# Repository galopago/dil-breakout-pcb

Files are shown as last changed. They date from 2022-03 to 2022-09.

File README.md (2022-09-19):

# BREAKOUT BOARDS FOR RF MODULES

Open source breakout boards for "stamp like" rf modules. Good for experimenting on a breadboard or to be used as sub-boards.

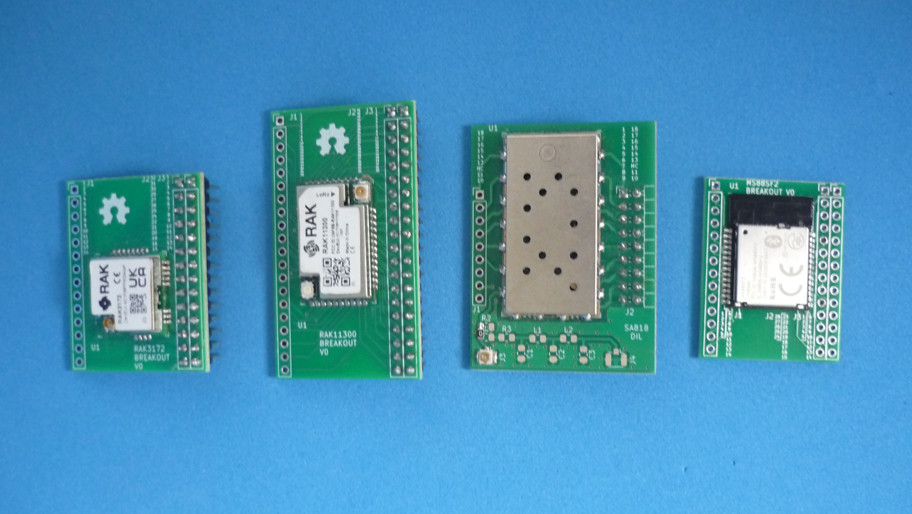
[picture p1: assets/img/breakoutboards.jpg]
BREAKBOARDS


Read this in other languages: [Español](/assets/markdown/README.es.md)

Main features:

* Every pin is accessible
* Compatible with solderless breadboard
* Double row header for maximizing free space on prototype boards

Breadboard                              | Space saver right angle                    | Space saver rised                           
----------------------------------------|--------------------------------------------|---------------------------------------------
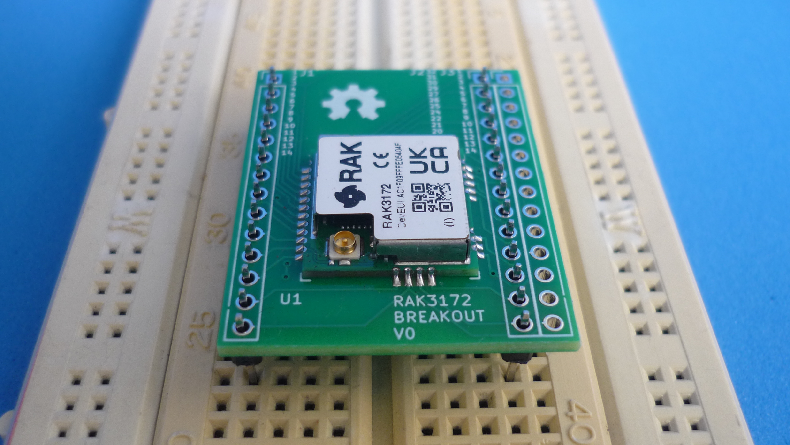
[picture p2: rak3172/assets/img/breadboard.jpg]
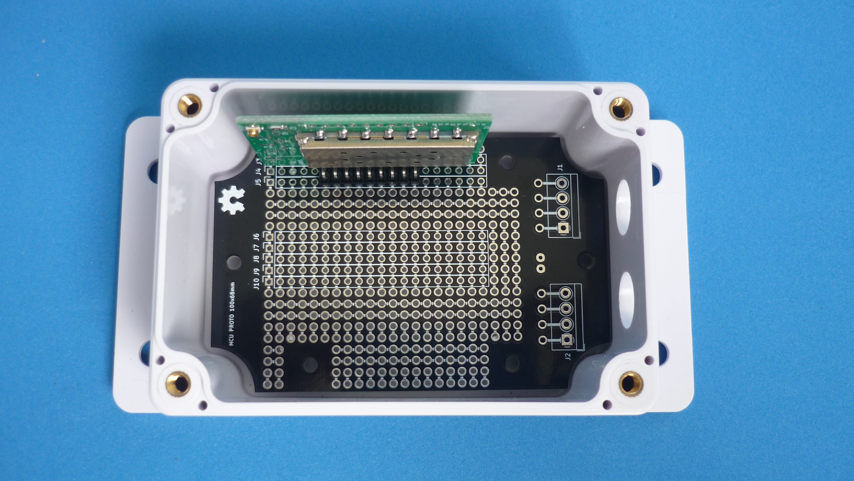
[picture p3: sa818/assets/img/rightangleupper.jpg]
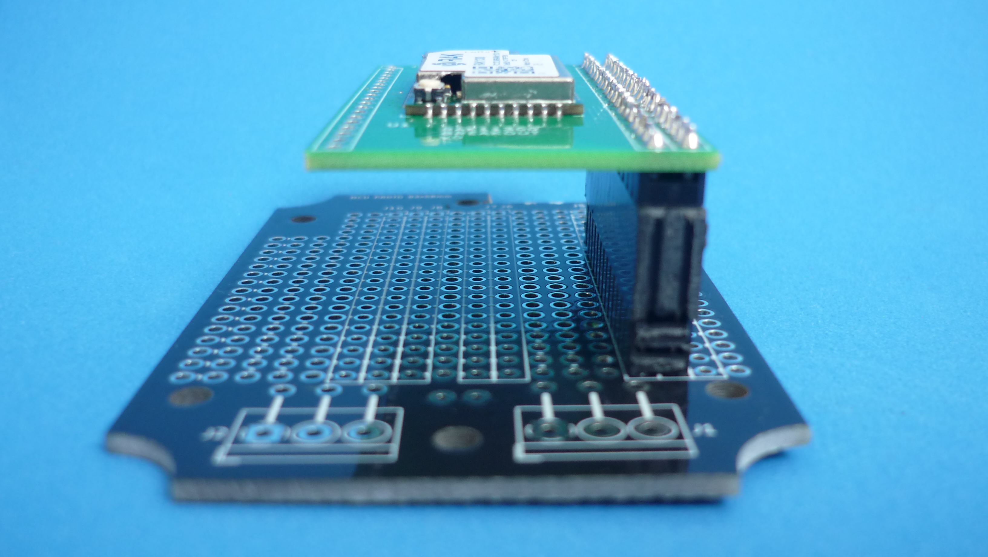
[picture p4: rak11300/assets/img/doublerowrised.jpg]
 |  | 

## Versions

There are several board versions, each one with different personalities

| HINT | CHIP | LINK 
|---|---|---
| RAK3172  | STM32WLE5CC | [RAK3172](/rak3172)  
| RAK11300 | RP2040+SX1262 | [RAK11300](/rak11300)  
| SA818 | RENESAS MCU ?+RDA1846 | [SA818](/sa818)
| MS88SF2  | nRF52840 | [MS88SF2](/ms88sf2)

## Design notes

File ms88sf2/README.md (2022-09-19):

# BREAKOUT BOARD FOR MS88SF2 MODULE

This board allows [Minew MS88SF2 modules](assets/pdf/MS88SF2.pdf) to be used on breadboard for prototyping. Open source and manufacturing files available. The main features are:

* Every pin is accessible
* Compatible with solderless breadboard
* Double row header for maximizing free space on prototype boards

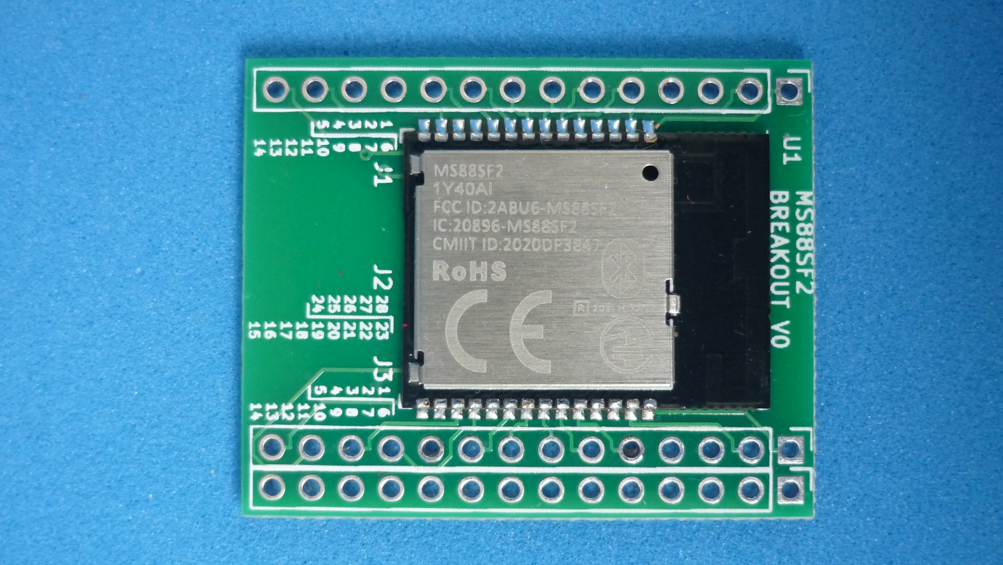
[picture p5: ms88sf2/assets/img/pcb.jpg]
PCB


## How to use this repository

The PCB was developed in KiCad V5.1,

## Directory structure

* The root folder contains template KiCad files: project, schematic and PCB 
* /library folder contains additional symbols needed to edit printed schematic
* /modules folder contains additional footprints needed to edit printed circuit board
* /gerber folder contains ready to manufacture files.
* /assets folder contains support files for reade.md

## PINOUT

layout

## BREADBOARD

Pitch compatible with solderless breadboard

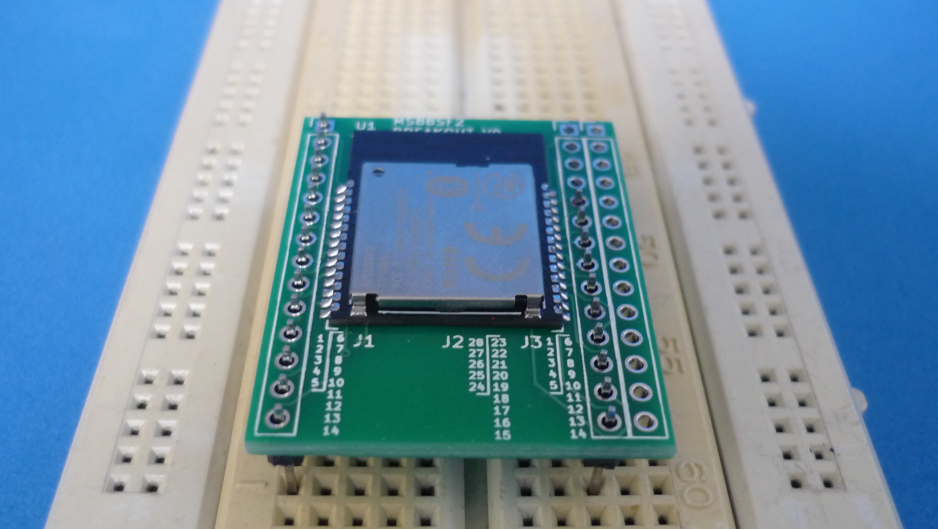
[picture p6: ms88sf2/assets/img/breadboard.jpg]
BREADBOARD


## DOUBLE ROW RIGHT ANGLE

Space saver option when enclosure's height allows it

 FRONT                             | SIDE                             | UPPER                            
-----------------------------------|----------------------------------|-----------------------------------
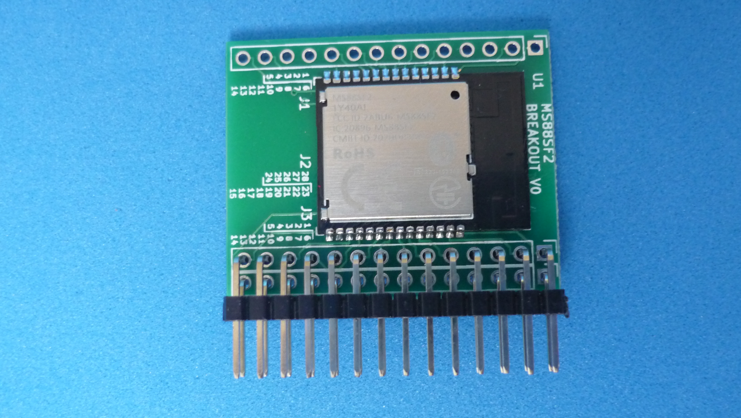
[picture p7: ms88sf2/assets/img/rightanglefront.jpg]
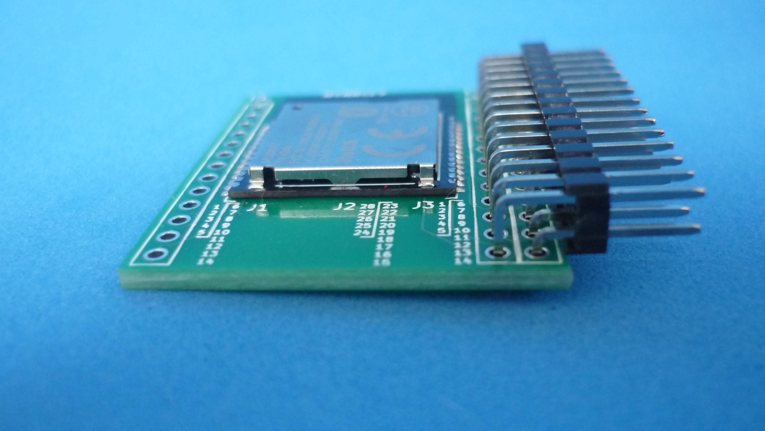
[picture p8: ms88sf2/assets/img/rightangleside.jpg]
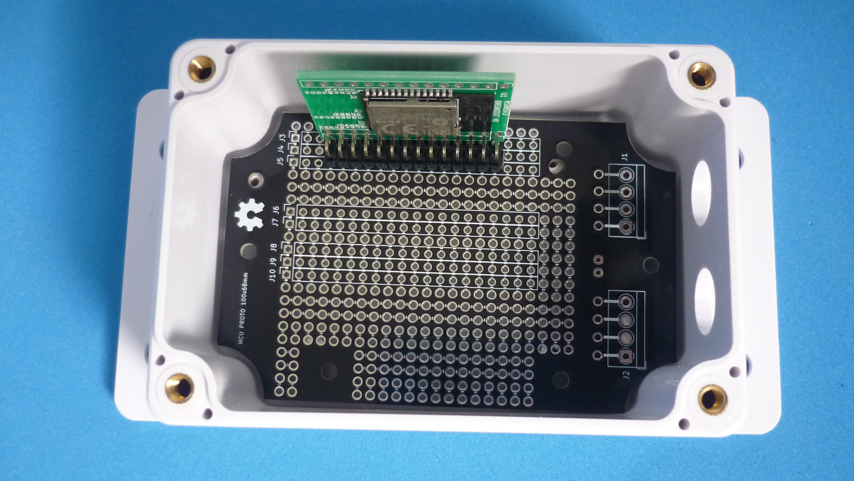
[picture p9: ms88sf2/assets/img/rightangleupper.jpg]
||

## DOUBLE ROW RISED

Space saver option for batteries or additional electronics. Uses long pin headers with spacers to reach the maximun allowable height

 SIDE                              | RISED                          
-----------------------------------|--------------------------------
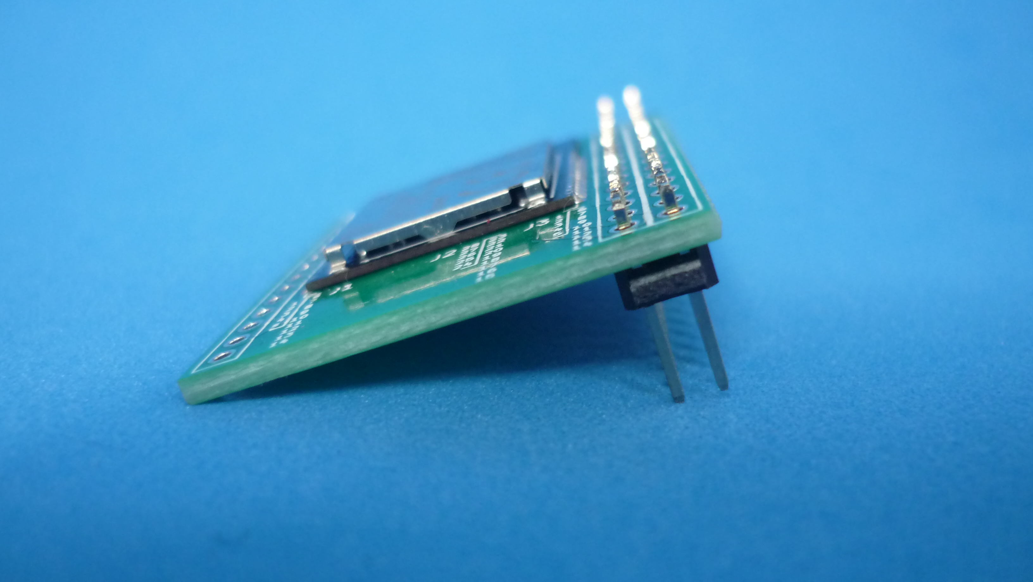
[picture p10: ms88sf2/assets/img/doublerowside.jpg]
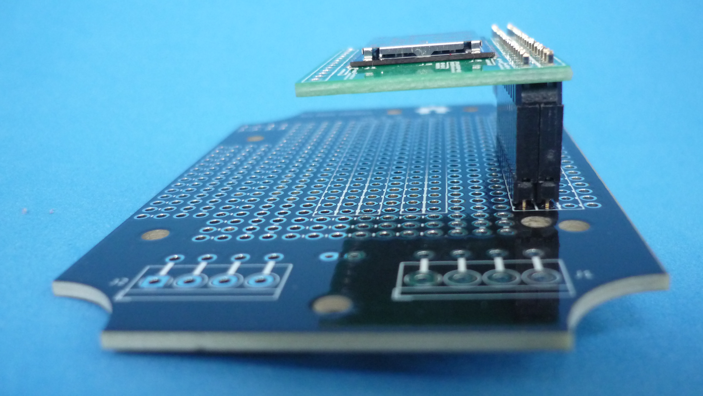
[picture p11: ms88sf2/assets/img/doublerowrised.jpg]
|

## PCB

 SINGLE                            | PANEL                          
-----------------------------------|--------------------------------
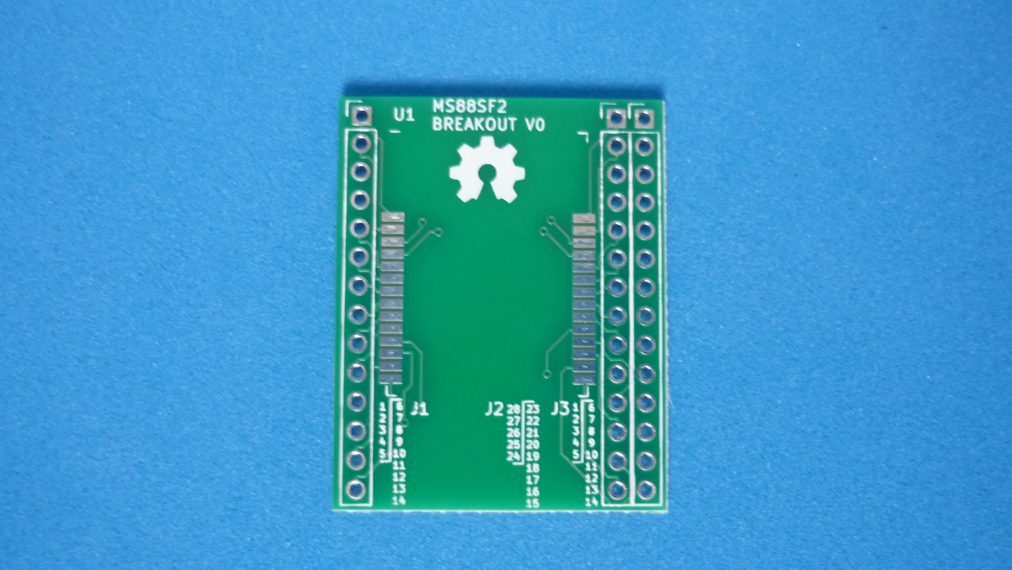
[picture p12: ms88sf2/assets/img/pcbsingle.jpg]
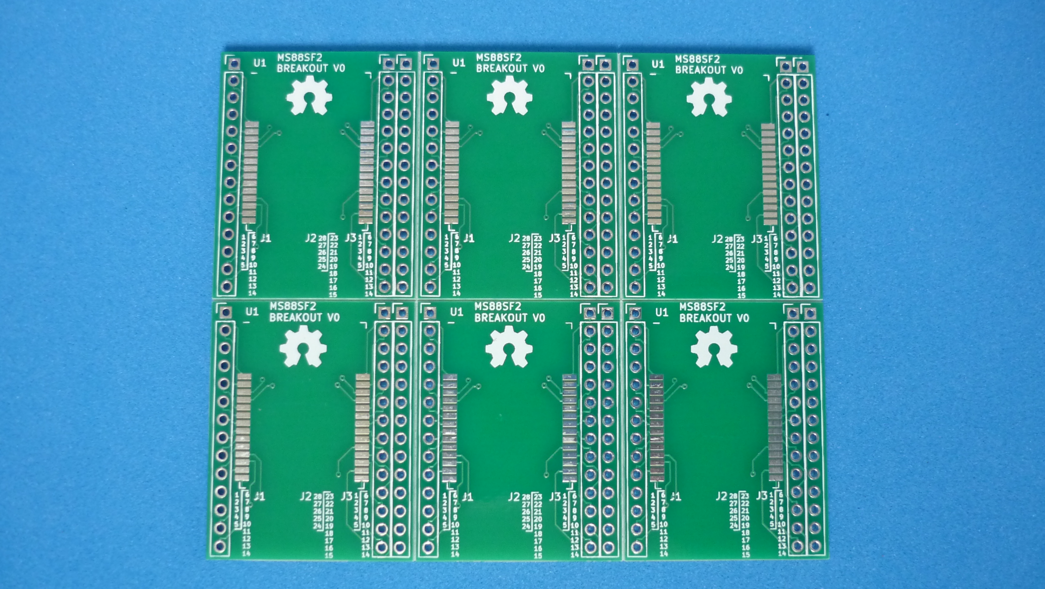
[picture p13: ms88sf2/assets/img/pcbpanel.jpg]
|

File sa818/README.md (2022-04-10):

# BREAKOUT BOARD FOR SA818 MODULE

This board allows [NiceRF SA818 modules](assets/pdf/SA818.pdf) to be used on breadboard for prototyping. Open source and manufacturing files available. The main features are:

* Every pin is accessible
* Compatible with solderless breadboard
* Double row header for maximizing free space on prototype boards
* Pads for U.Fl RF connector
* Pads for custom output pi filter

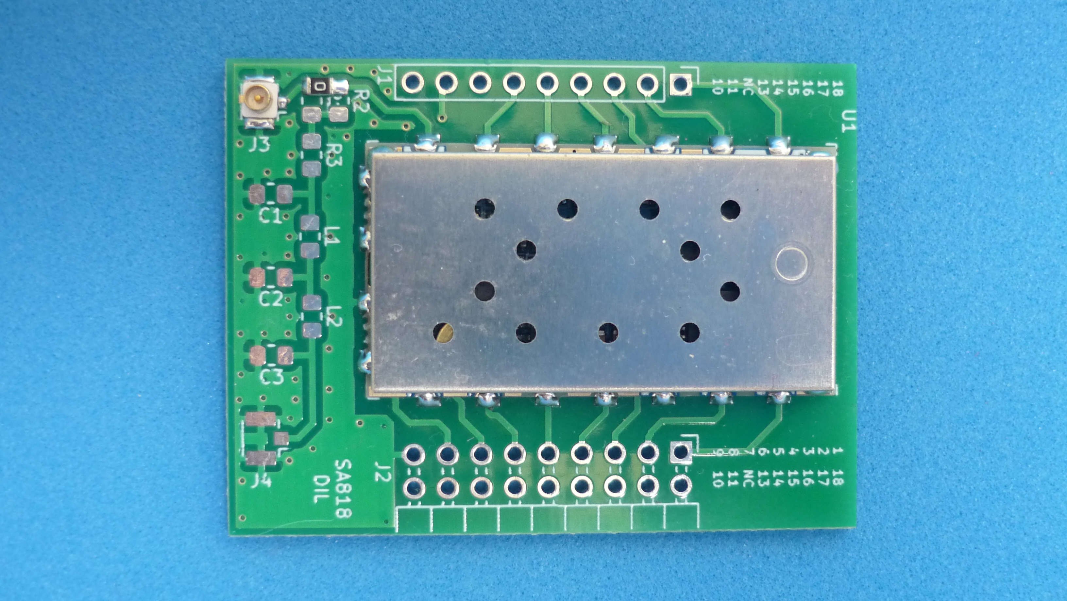
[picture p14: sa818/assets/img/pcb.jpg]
PCB


## How to use this repository

The PCB was developed in KiCad V5.1,

## Directory structure

* The root folder contains template KiCad files: project, schematic and PCB 
* /library folder contains additional symbols needed to edit printed schematic
* /modules folder contains additional footprints needed to edit printed circuit board
* /gerber folder contains ready to manufacture files.
* /assets folder contains support files for reade.md

## PINOUT

layout

## BREADBOARD

Pitch compatible with solderless breadboard

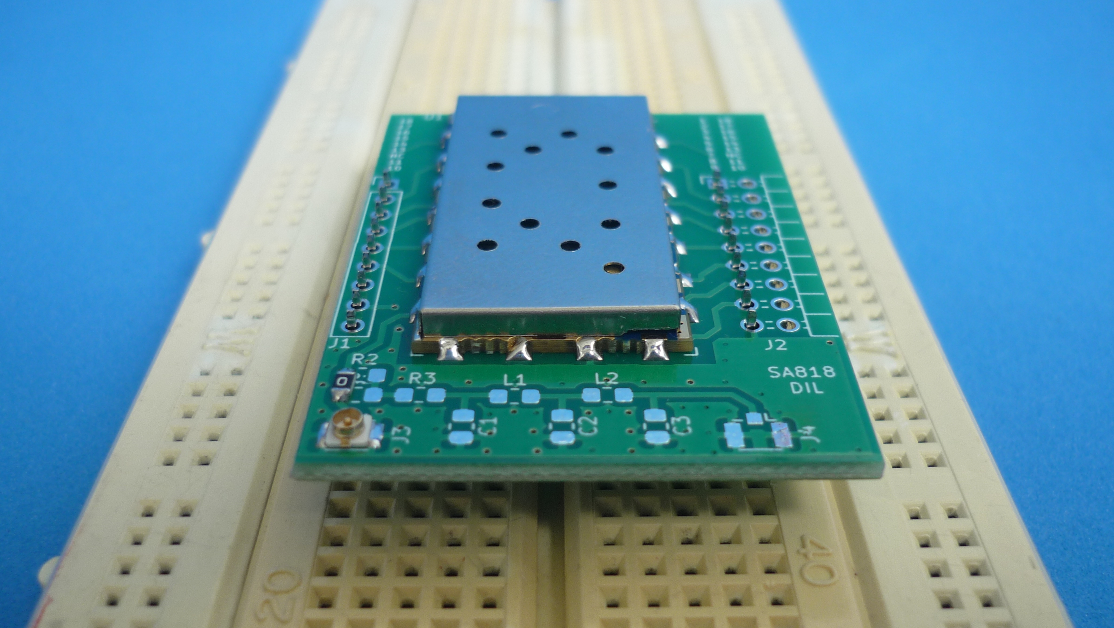
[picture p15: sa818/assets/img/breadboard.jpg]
BREADBOARD


## DOUBLE ROW RIGHT ANGLE

Space saver option when enclosure's height allows it

 FRONT                             | SIDE                             | UPPER                            
-----------------------------------|----------------------------------|-----------------------------------
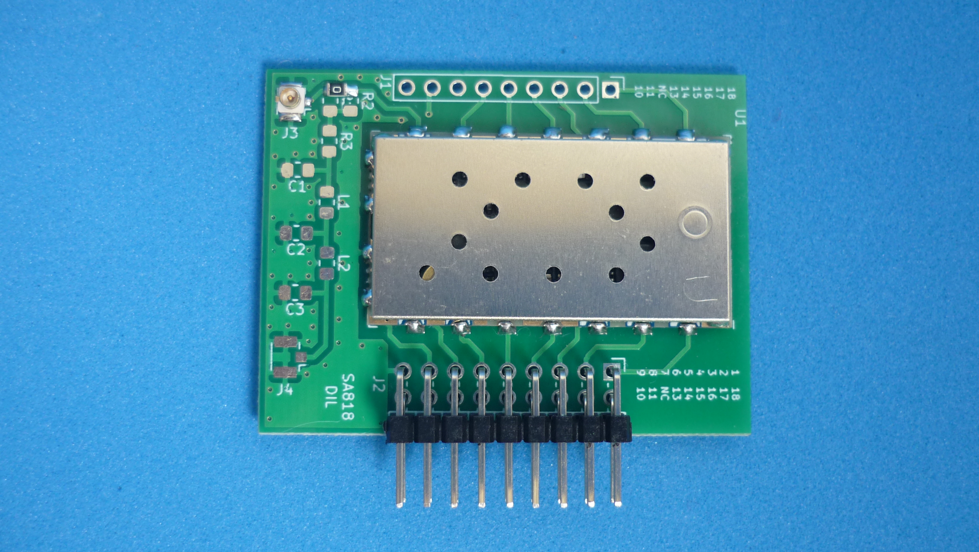
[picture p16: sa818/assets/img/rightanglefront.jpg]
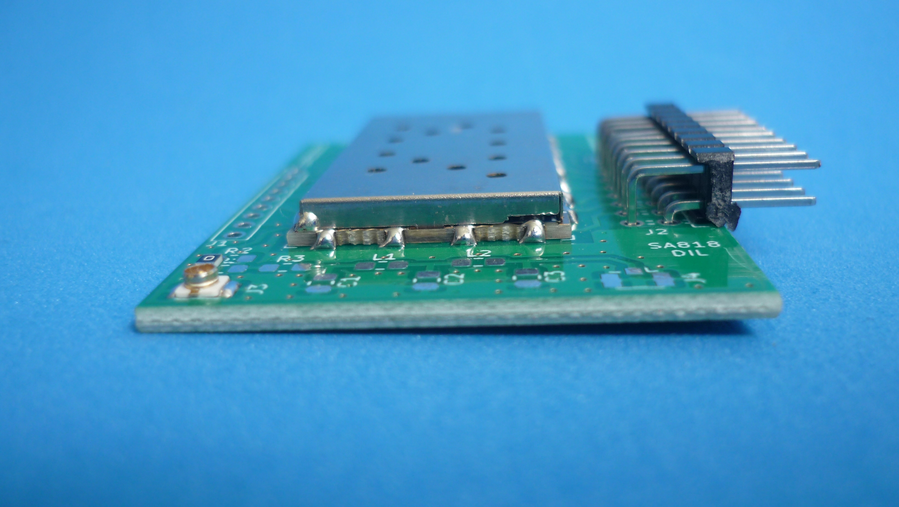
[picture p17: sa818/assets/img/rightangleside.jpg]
||

## DOUBLE ROW RISED

Space saver option for batteries or additional electronics. Uses long pin headers with spacers to reach the maximun allowable height

 SIDE                              | RISED                          
-----------------------------------|--------------------------------
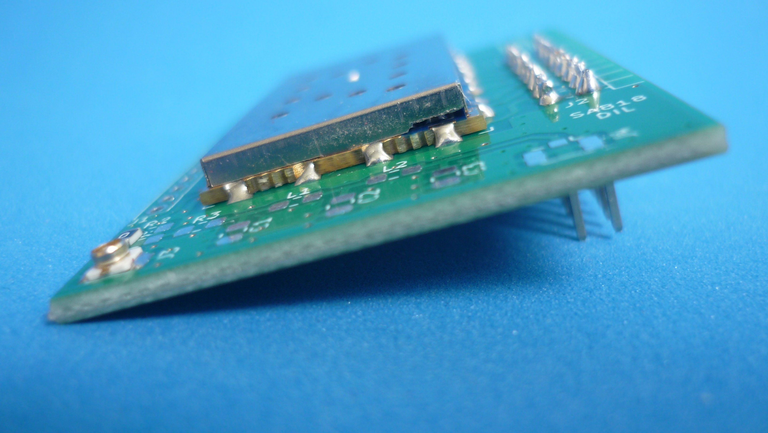
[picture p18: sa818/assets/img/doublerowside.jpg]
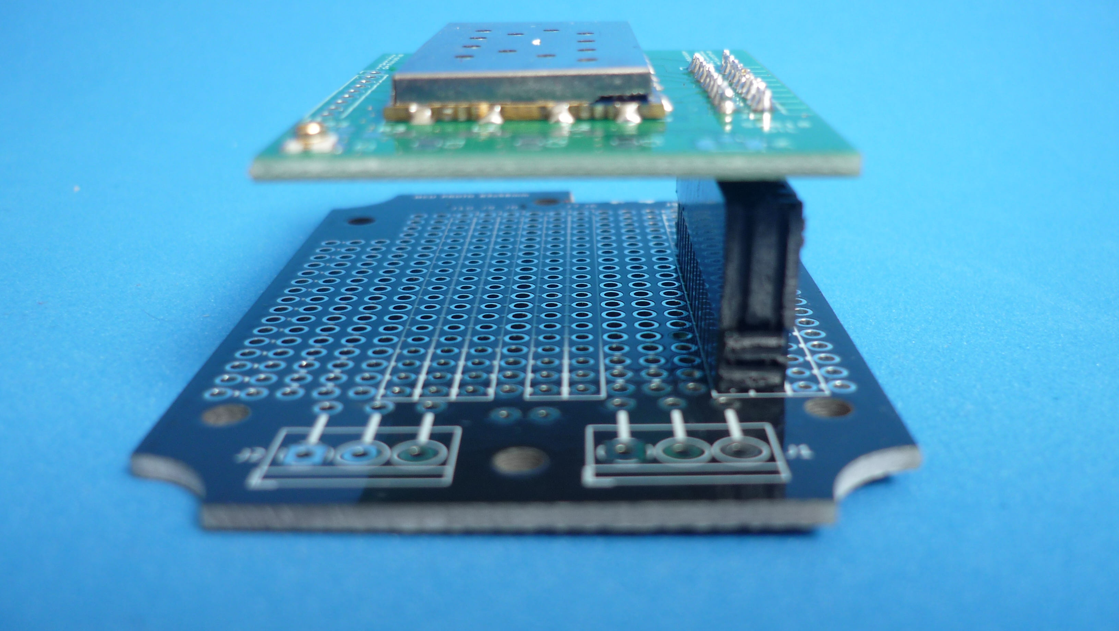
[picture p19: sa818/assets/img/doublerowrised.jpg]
|

## PCB

 SINGLE                            | PANEL                          
-----------------------------------|--------------------------------
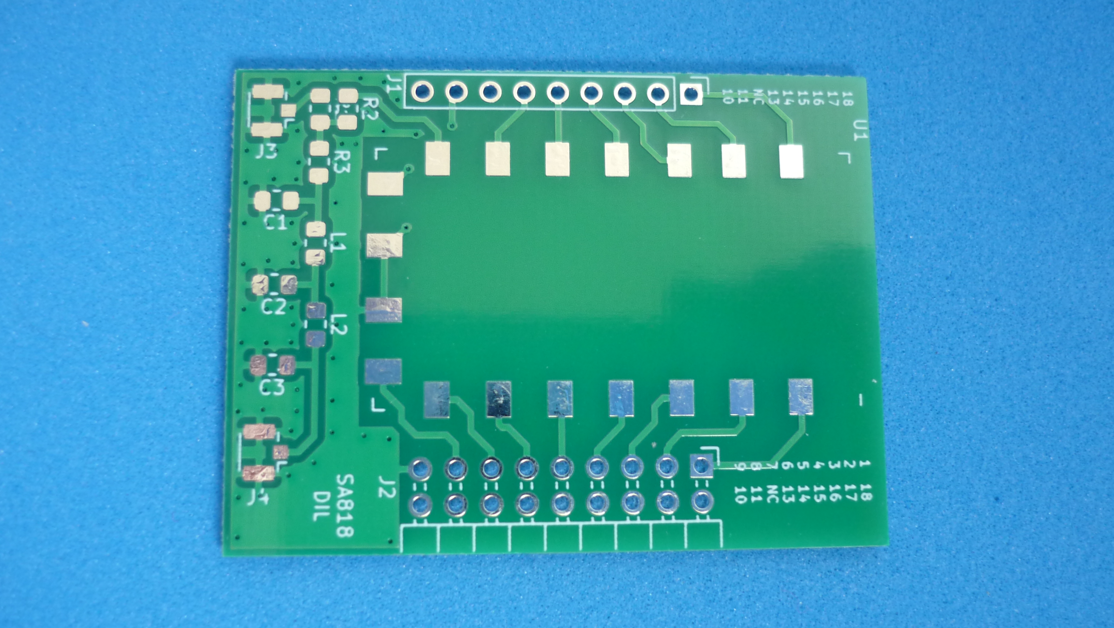
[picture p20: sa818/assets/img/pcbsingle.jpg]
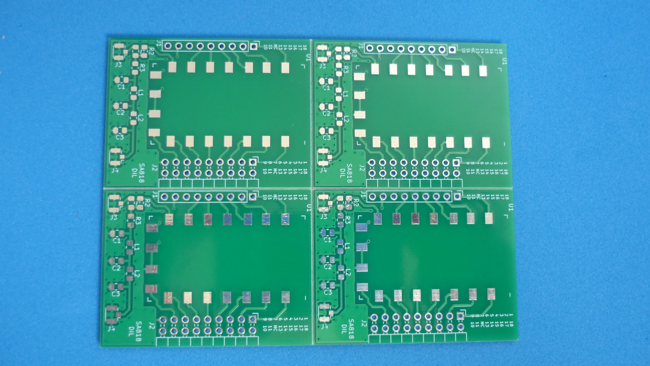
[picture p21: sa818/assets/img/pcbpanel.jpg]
|

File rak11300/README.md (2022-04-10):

# BREAKOUT BOARD FOR RAK11300 MODULE

This board allows [RAK Wireless 11300 modules](assets/pdf/RAK11300.pdf) to be used on breadboard for prototyping. Open source and manufacturing files available. The main features are:

* Every pin is accessible
* Compatible with solderless breadboard
* Double row header for maximizing free space on prototype boards

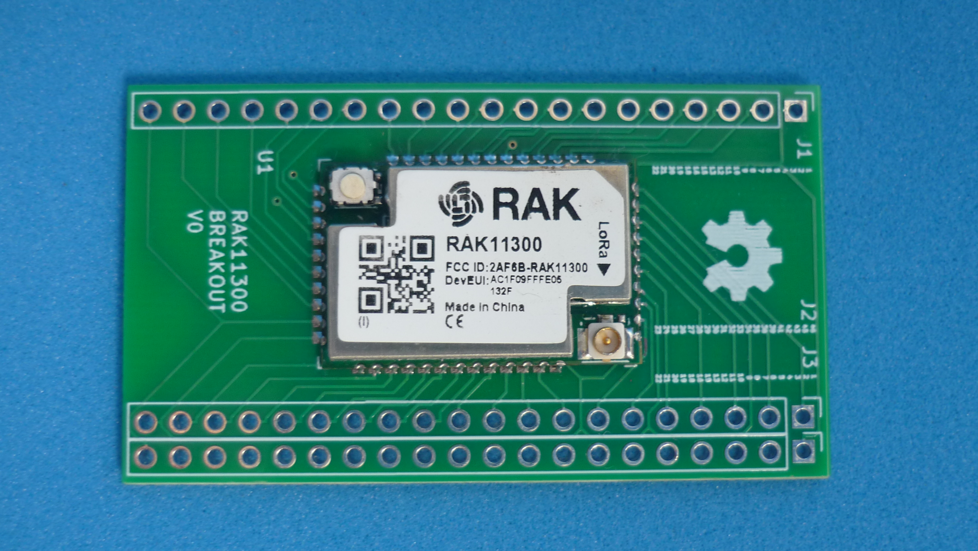
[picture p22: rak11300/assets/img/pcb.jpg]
PCB


## How to use this repository

The PCB was developed in KiCad V5.1,

## Directory structure

* The root folder contains template KiCad files: project, schematic and PCB 
* /library folder contains additional symbols needed to edit printed schematic
* /modules folder contains additional footprints needed to edit printed circuit board
* /gerber folder contains ready to manufacture files.
* /assets folder contains support files for reade.md

## PINOUT

layout

## BREADBOARD

Pitch compatible with solderless breadboard

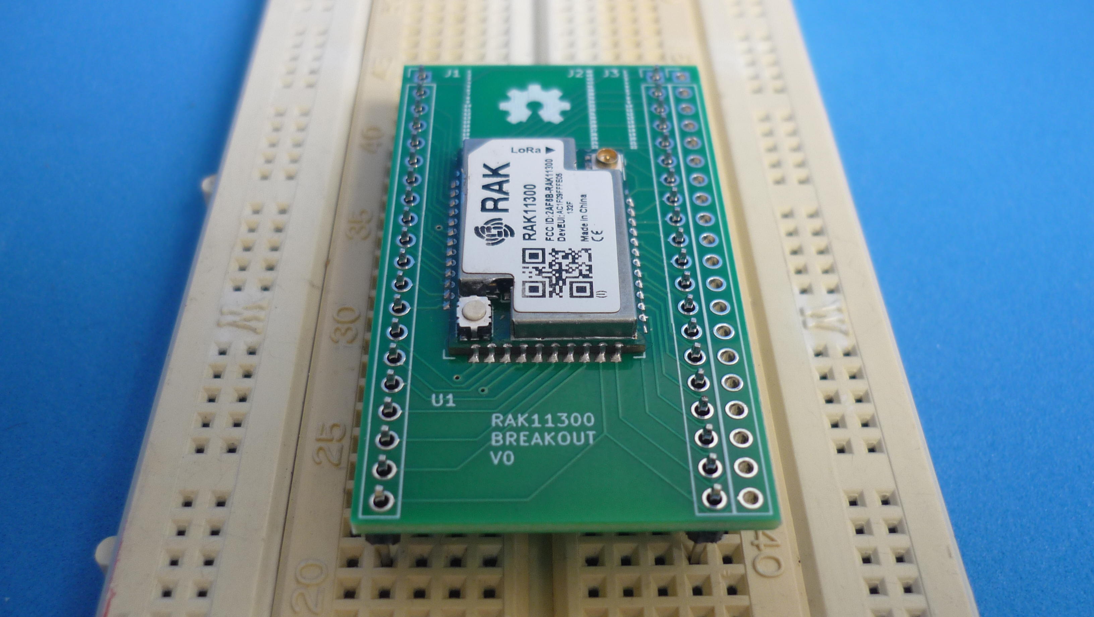
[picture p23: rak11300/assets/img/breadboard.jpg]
BREADBOARD


## DOUBLE ROW RIGHT ANGLE

Space saver option when enclosure's height allows it

 FRONT                             | SIDE                             | UPPER                            
-----------------------------------|----------------------------------|-----------------------------------
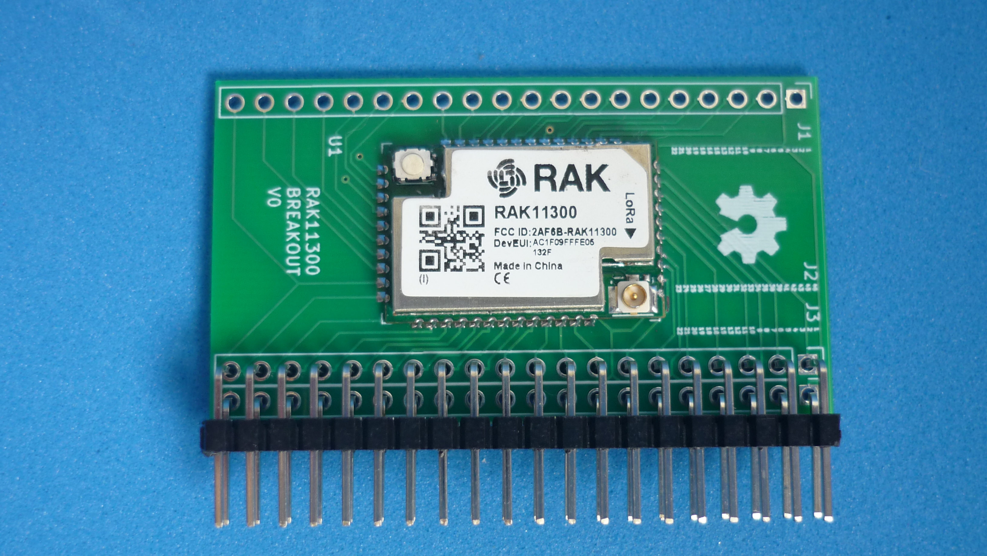
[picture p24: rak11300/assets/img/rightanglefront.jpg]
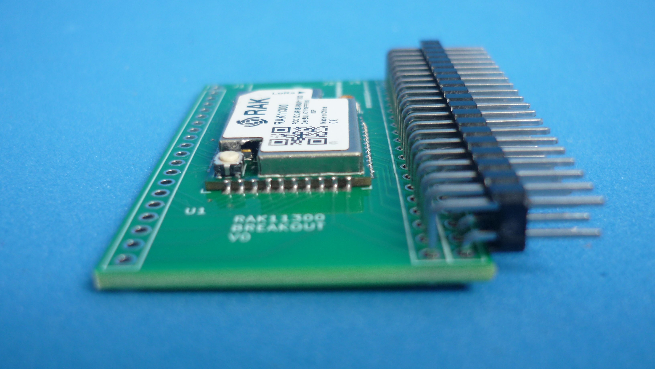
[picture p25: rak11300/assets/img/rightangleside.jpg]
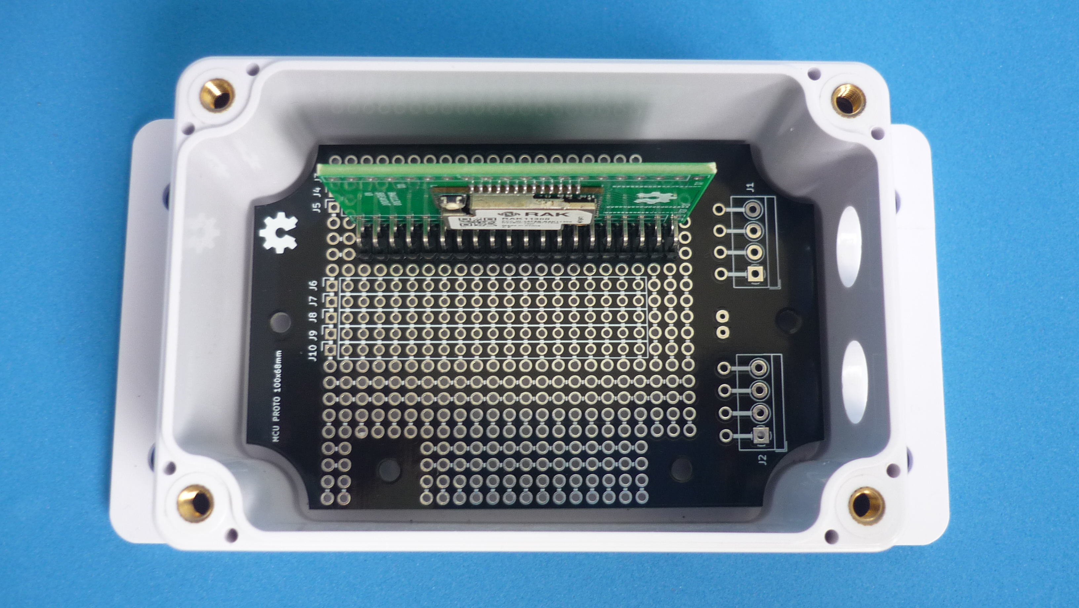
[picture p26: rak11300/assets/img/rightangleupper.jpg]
||

## DOUBLE ROW RISED

Space saver option for batteries or additional electronics. Uses long pin headers with spacers to reach the maximun allowable height

 SIDE                              | RISED                          
-----------------------------------|--------------------------------
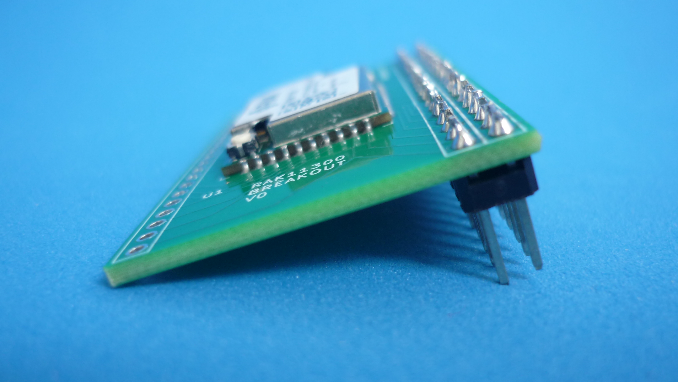
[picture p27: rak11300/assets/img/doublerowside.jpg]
|

## PCB

 SINGLE                            | PANEL                          
-----------------------------------|--------------------------------
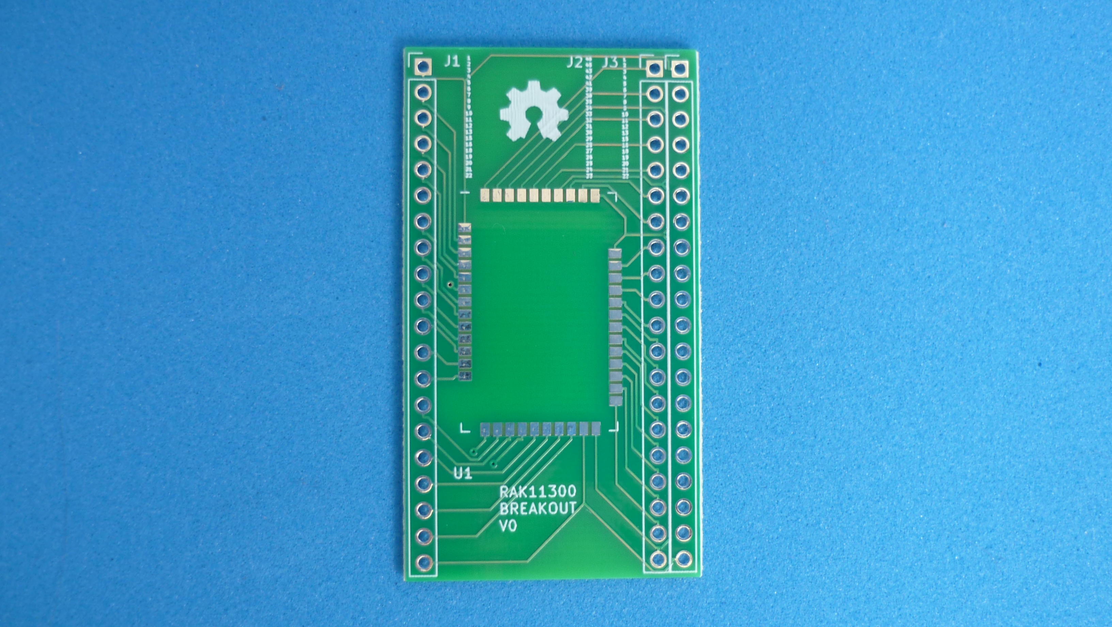
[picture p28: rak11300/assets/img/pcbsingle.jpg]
|

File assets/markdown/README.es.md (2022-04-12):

# TARJETA BREAKOUT PARA MODULOS RF

Tarjeta breakout Open source para modulos rf tipo "estampilla". Utiles para experimentar en protoboard o para ser usada como sub-tarjeta.

BREAKBOARDS

Lea esto en otros idiomas: [English](../../README.md)

Principales caracteristicas:

* Todos los pines son accesibles
* Compatible con protoboards
* Header de doble hilera para maximizar el espacio libre disponible en tarjetas de prototipado

Protoboard                              | Modo economiza espacio 90 grados           | Modo economiza espacio elevado
----------------------------------------|--------------------------------------------|---------------------------------------------
 |  | 

## Versiones

Existen varias versiones de la tarjeta, cada una tiene su propia personalidad

| DESCRIPCION | CHIP | ENLACE 
|---|---|---
| RAK3172 | STM32WLE5CC | [RAK3172](/rak3172)  
| RAK11300 | RP2040+SX1262 | [RAK11300](/rak11300)  
| SA818 | RENESAS MCU ?+RDA1846 | [SA818](/sa818)

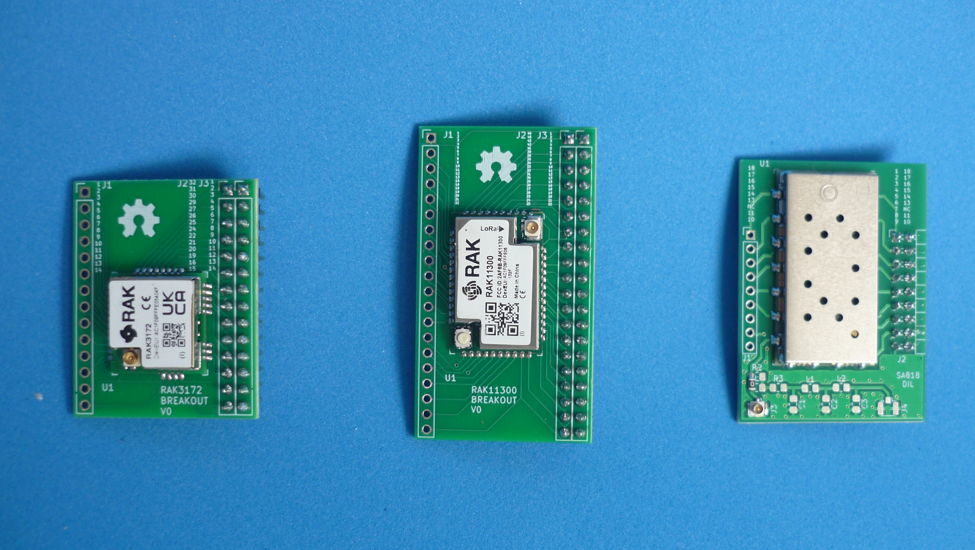
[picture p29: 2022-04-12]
assets/img/_breakoutboards.jpg

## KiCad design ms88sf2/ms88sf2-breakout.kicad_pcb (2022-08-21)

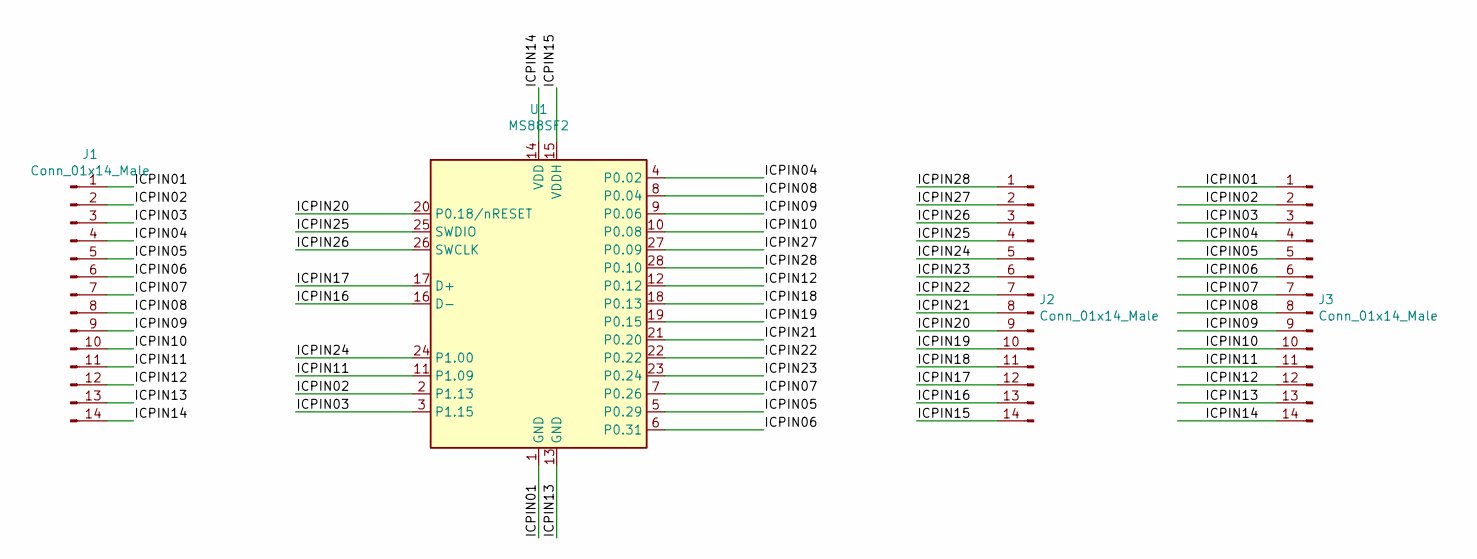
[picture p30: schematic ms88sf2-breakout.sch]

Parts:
J1, J2, J3: Conn_01x14_Male; PinHeader_1x14_P2.54mm_Vertical
U1: MS88SF2

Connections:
/ICPIN01: J1.1, J3.1, U1.1 (GND)
/ICPIN02: J1.2, J3.2, U1.2 (P1.13)
/ICPIN03: J1.3, J3.3, U1.3 (P1.15)
/ICPIN04: J1.4, J3.4, U1.4 (P0.02)
/ICPIN05: J1.5, J3.5, U1.5 (P0.29)
/ICPIN06: J1.6, J3.6, U1.6 (P0.31)
/ICPIN07: J1.7, J3.7, U1.7 (P0.26)
/ICPIN08: J1.8, J3.8, U1.8 (P0.04)
/ICPIN09: J1.9, J3.9, U1.9 (P0.06)
/ICPIN10: J1.10, J3.10, U1.10 (P0.08)
/ICPIN11: J1.11, J3.11, U1.11 (P1.09)
/ICPIN12: J1.12, J3.12, U1.12 (P0.12)
/ICPIN13: J1.13, J3.13, U1.13 (GND)
/ICPIN14: J1.14, J3.14, U1.14 (VDD)
/ICPIN15: J2.14, U1.15 (VDDH)
/ICPIN16: J2.13, U1.16 (D-)
/ICPIN17: J2.12, U1.17 (D+)
/ICPIN18: J2.11, U1.18 (P0.13)
/ICPIN19: J2.10, U1.19 (P0.15)
/ICPIN20: J2.9, U1.20 (P0.18/nRESET)
/ICPIN21: J2.8, U1.21 (P0.20)
/ICPIN22: J2.7, U1.22 (P0.22)
/ICPIN23: J2.6, U1.23 (P0.24)
/ICPIN24: J2.5, U1.24 (P1.00)
/ICPIN25: J2.4, U1.25 (SWDIO)
/ICPIN26: J2.3, U1.26 (SWCLK)
/ICPIN27: J2.2, U1.27 (P0.09)
/ICPIN28: J2.1, U1.28 (P0.10)

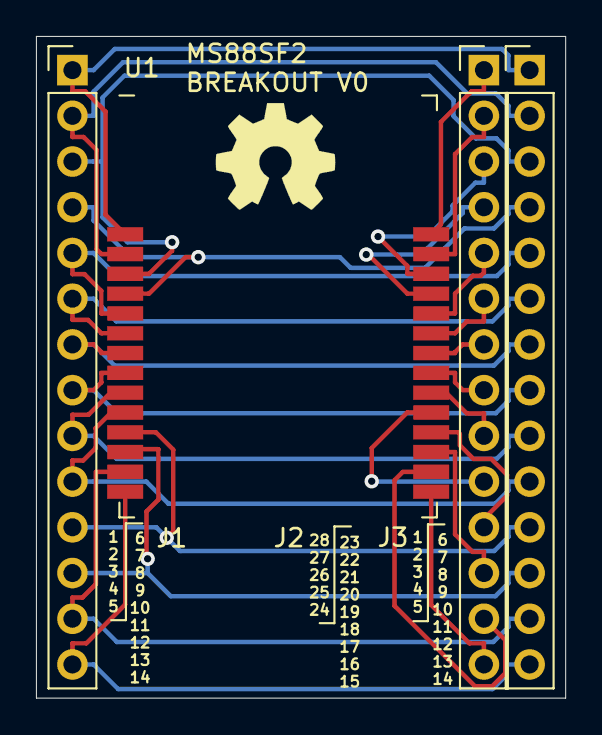
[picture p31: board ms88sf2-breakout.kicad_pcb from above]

Board: 2 copper layers, 29.4 x 36.8 mm, 4 parts (0 on the bottom side), 28 nets.

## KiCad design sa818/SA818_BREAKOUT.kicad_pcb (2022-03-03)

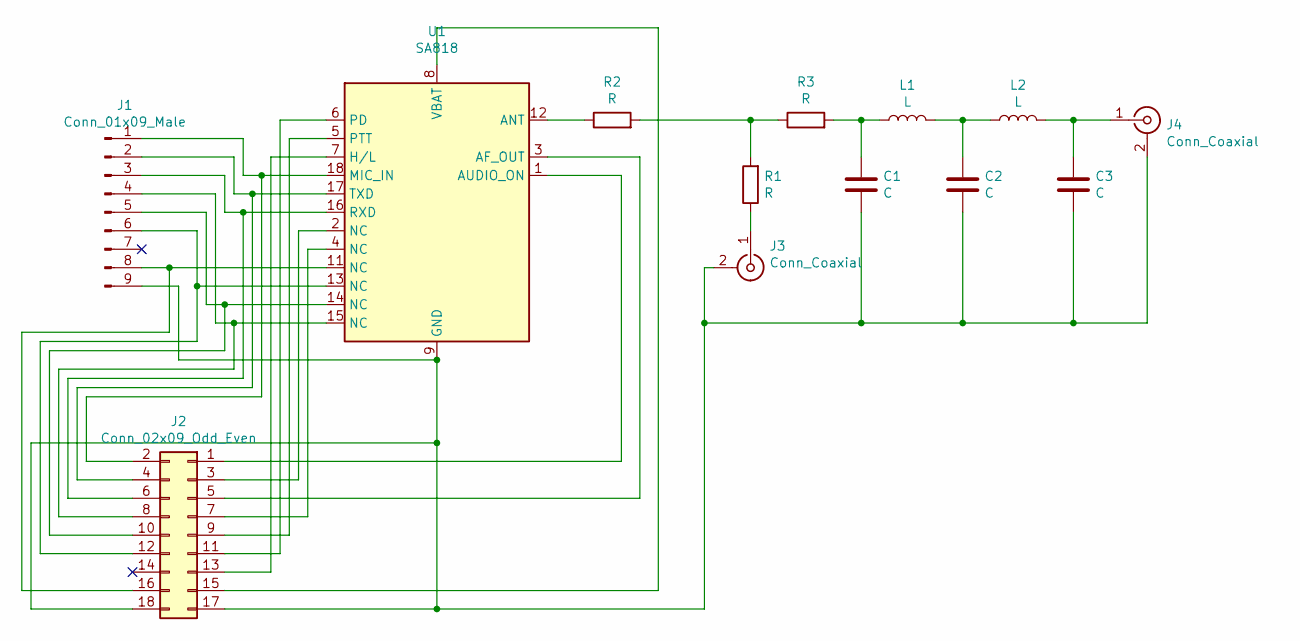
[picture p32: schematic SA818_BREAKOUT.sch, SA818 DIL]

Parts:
C1, C2, C3: C; C_0805_2012Metric_Pad1.15x1.40mm_HandSolder
J1: Conn_01x09_Male; PinHeader_1x09_P2.54mm_Vertical
J2: Conn_02x09_Odd_Even; PinHeader_2x09_P2.54mm_Horizontal
J3, J4: Conn_Coaxial; U.FL_Hirose_U.FL-R-SMT-1_Vertical
L1, L2: L; L_0805_2012Metric_Pad1.15x1.40mm_HandSolder
R1, R2, R3: R; R_0805_2012Metric_Pad1.15x1.40mm_HandSolder
U1: SA818

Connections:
unnamed: C1.1, L1.1, R3.2
unnamed: C1.2, C2.2, C3.2, J1.9, J2.17, J2.18, J3.2 (Ext), J4.2 (Ext), U1.9 (GND), U1.10 (GND)
unnamed: C2.1, L1.2, L2.1
unnamed: C3.1, J4.1 (In), L2.2
unnamed: J1.1, J2.2, U1.18 (MIC_IN)
unnamed: J1.2, J2.4, U1.17 (TXD)
unnamed: J1.3, J2.6, U1.16 (RXD)
unnamed: J1.4, J2.8, U1.15 (NC)
unnamed: J1.5, J2.10, U1.14 (NC)
unnamed: J1.6, J2.12, U1.13 (NC)
unnamed: J1.8, J2.16, U1.11 (NC)
unnamed: J2.1, U1.1 (AUDIO_ON)
unnamed: J2.3, U1.2 (NC)
unnamed: J2.5, U1.3 (AF_OUT)
unnamed: J2.7, U1.4 (NC)
unnamed: J2.9, U1.5 (PTT)
unnamed: J2.11, U1.6 (PD)
unnamed: J2.13, U1.7 (H/L)
unnamed: J2.15, U1.8 (VBAT)
unnamed: J3.1 (In), R1.1
unnamed: R1.2, R2.2, R3.1
unnamed: R2.1, U1.12 (ANT)

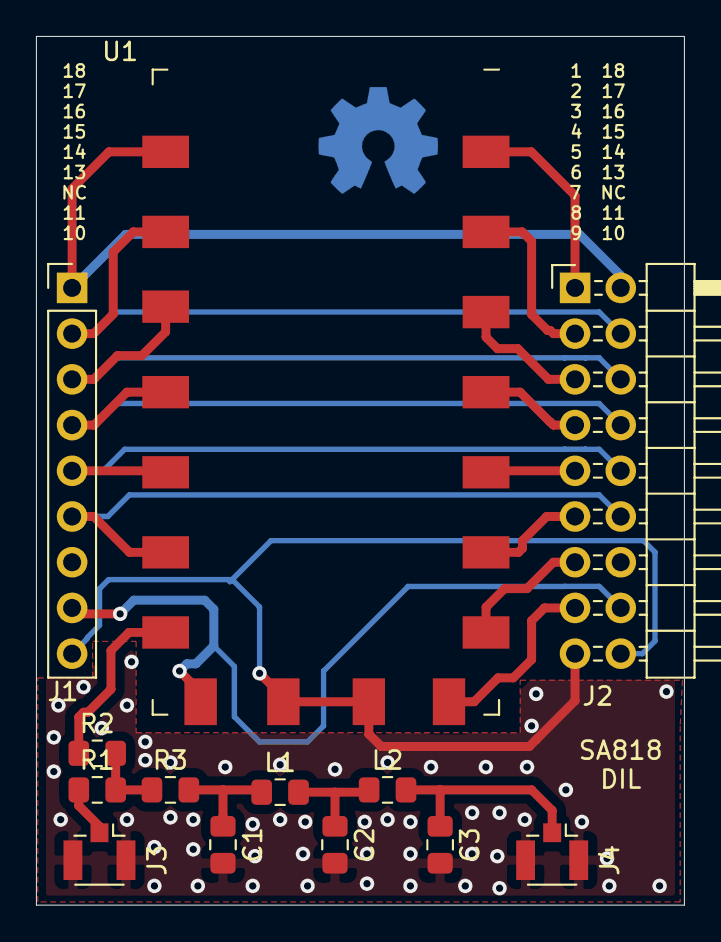
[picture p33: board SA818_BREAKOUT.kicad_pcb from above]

Board: 2 copper layers, 36.0 x 48.3 mm, 13 parts (0 on the bottom side), 22 nets.

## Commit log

2022-03-01 starting project RAK3712
    [RAK3712_BREAKOUT.kicad_pcb, RAK3712_BREAKOUT.sch]
2022-03-01 started RAK3172 symbol
    [RAK3712_BREAKOUT.sch]
2022-03-01 sch:(DIL_BREAKOUT_PCB RAK 3712)changing pins
    [RAK3712_BREAKOUT.sch]
2022-03-02 sch:(DIL_BREAKOUT_PCB RAK 3712)pins arranged
    [RAK3712_BREAKOUT.sch]
2022-03-02 sch:(DIL_BREAKOUT_PCB RAK 3712)shrinked
    [RAK3712_BREAKOUT.sch]
2022-03-02 sch:(DIL_BREAKOUT_PCB RAK 3712)tied to headers
    [RAK3712_BREAKOUT.sch]
2022-03-02 foot:(DIL_BREAKOUT_PCB RAK 3712)ready for route
    [RAK3712_BREAKOUT.kicad_pcb, RAK3712_BREAKOUT.sch]
2022-03-02 foot:(DIL_BREAKOUT_PCB RAK 3712)first route
    [RAK3712_BREAKOUT.dsn, RAK3712_BREAKOUT.kicad_pcb]
2022-03-02 pcb:(DIL_BREAKOUT_PCB RAK 3712)routed!
    [RAK3712_BREAKOUT.dsn, RAK3712_BREAKOUT.kicad_pcb]
2022-03-02 pcb-sch:(DIL_BREAKOUT_PCB RAK 3712)changed name!
    [RAK3712_BREAKOUT.sch]
2022-03-02 proj:(DIL_BREAKOUT_PCB RAK 3712)changed project filenames
    [RAK3172_BREAKOUT.kicad_pcb, RAK3172_BREAKOUT.sch]
2022-03-02 pcb:(DIL_BREAKOUT_PCB RAK 3172) minor adjustments
    [RAK3172_BREAKOUT.kicad_pcb]
2022-03-02 pcb:(DIL_BREAKOUT_PCB RAK 3172) silks headers
    [RAK3172_BREAKOUT.kicad_pcb]
2022-03-02 pcb:(DIL_BREAKOUT_PCB RAK 3172)single gerber
    [RAK3172_BREAKOUT-B_Cu.gbr, RAK3172_BREAKOUT-B_Mask.gbr, RAK3172_BREAKOUT-B_SilkS.gbr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]
2022-03-02 pcb:(DIL_BREAKOUT_PCB RAK 3172)panel gerber
    [RAK3172_BREAKOUT_PANEL-B_Cu.gbr, RAK3172_BREAKOUT_PANEL-B_Mask.gbr, RAK3172_BREAKOUT_PANEL-B_SilkS.gbr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]
2022-03-02 pcb:(DIL_BREAKOUT_PCB RAK 11300)expanded and routed
    [RAK11300_BREAKOUT.dsn, RAK11300_BREAKOUT.kicad_pcb, RAK11300_BREAKOUT.sch]
2022-03-03 pcb:(DIL_BREAKOUT_PCB RAK 11300)single gerber
    [RAK11300_BREAKOUT-B_Cu.gbr, RAK11300_BREAKOUT-B_Mask.gbr, RAK11300_BREAKOUT-B_SilkS.gbr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]
2022-03-03 pcb:(DIL_BREAKOUT_PCB RAK 11300)panel gerber
    [RAK11300_BREAKOUT_PANEL-B_Cu.gbr, RAK11300_BREAKOUT_PANEL-B_Mask.gbr, RAK11300_BREAKOUT_PANEL-B_SilkS.gbr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]
2022-03-03 proj:(DIL_BREAKOUT_PCB SA 818)migrated project
    [SA818_BREAKOUT-B_Cu.gbr, SA818_BREAKOUT-B_Mask.gbr, SA818_BREAKOUT-B_SilkS.gbr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]
2022-04-09 doc:(dil-breakout)renamed folders
    [RAK11300_BREAKOUT-B_Cu.gbr, RAK11300_BREAKOUT-B_Mask.gbr, RAK11300_BREAKOUT-B_SilkS.gbr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]
2022-04-09 doc:(dil-breakout rak3172)readme pcb
2022-04-10 doc:(dil-breakout sa810)pcb pics
2022-08-21 started MS88SF2
    [ms88sf2-breakout.kicad_pcb, ms88sf2-breakout.sch]
2022-08-21 MS88SF2 routed
    [ms88sf2-breakout.dsn, ms88sf2-breakout.kicad_pcb, ms88sf2-breakout.sch]
2022-08-21 single gerber
    [ms88sf2-breakout-B_Cu.gbr, ms88sf2-breakout-B_Mask.gbr, ms88sf2-breakout-B_SilkS.gbr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]
